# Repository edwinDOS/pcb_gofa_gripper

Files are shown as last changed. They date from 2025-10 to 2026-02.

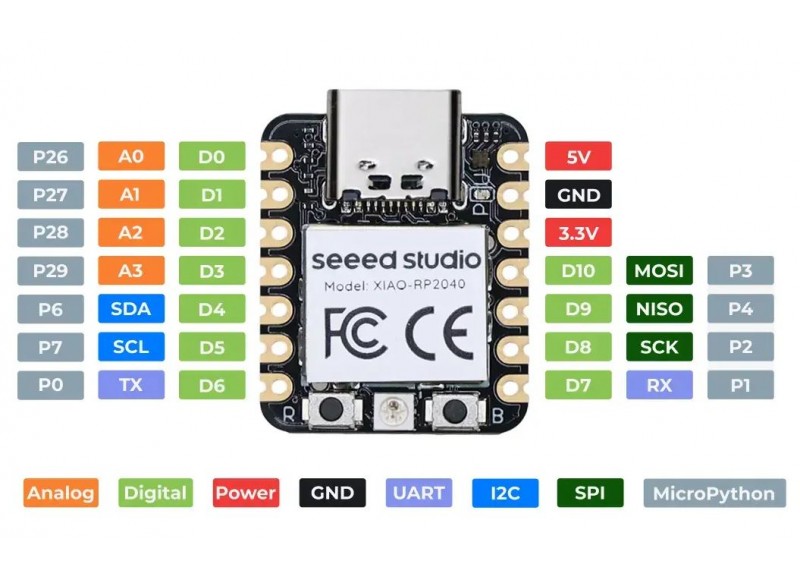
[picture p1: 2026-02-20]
XIAO_RP2040/ArduinoCode/seeed-studio-xiao-rp2040.jpg

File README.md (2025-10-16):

# pcb_gofa_gripper
This repository contains the PCB design for the ABB GOFA Gripper at UC3M

Desarrollado con:

Application: KiCad x64 on x64

Version: 9.0.1, release build

Libraries:
	wxWidgets 3.2.6
	FreeType 2.13.3
	HarfBuzz 10.2.0
	FontConfig 2.15.0
	libcurl/8.11.1-DEV Schannel zlib/1.3.1

Platform: Windows 10 (compilación 19045), edición de 64 bits, 64 bit, Little endian, wxMSW

Build Info:
	Date: Mar 30 2025 01:11:30
	wxWidgets: 3.2.6 (wchar_t,wx containers)
	Boost: 1.86.0
	OCC: 7.8.1
	Curl: 8.11.1-DEV
	ngspice: 44
	Compiler: Visual C++ 1942 without C++ ABI
	KICAD_IPC_API=ON

Locale: 
	Lang: es_ES
	Enc: UTF-8
	Num: 1.234,5
	Encoded кΩ丈: D0BACEA9E4B888 (sys), D0BACEA9E4B888 (utf8)

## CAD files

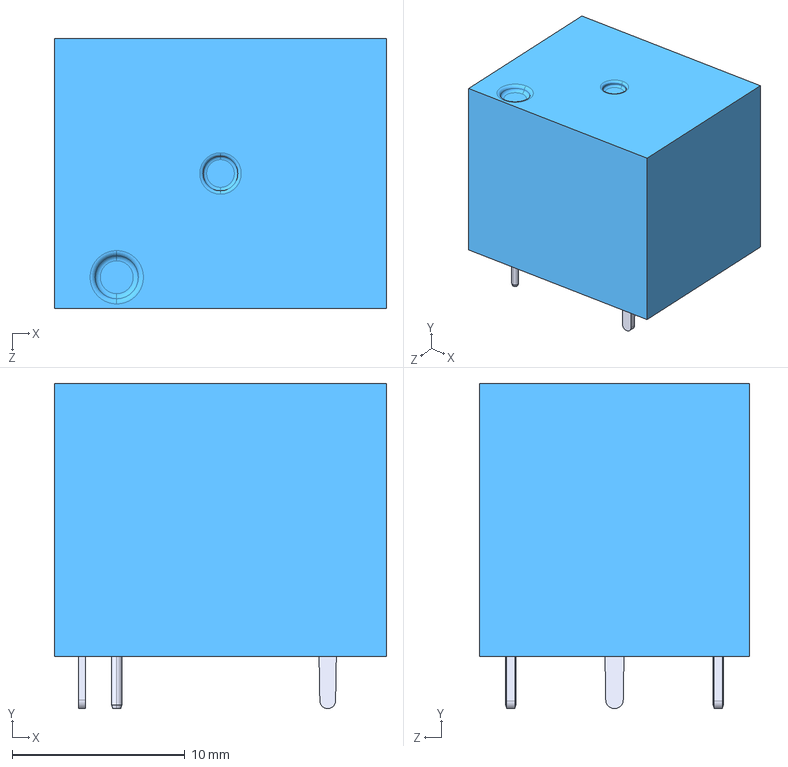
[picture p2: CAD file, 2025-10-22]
ArduinoNano/SRD-05VDC-SL-C/SRD-05VDC-SL-C.step
19.2 x 18.8 x 15.6 mm

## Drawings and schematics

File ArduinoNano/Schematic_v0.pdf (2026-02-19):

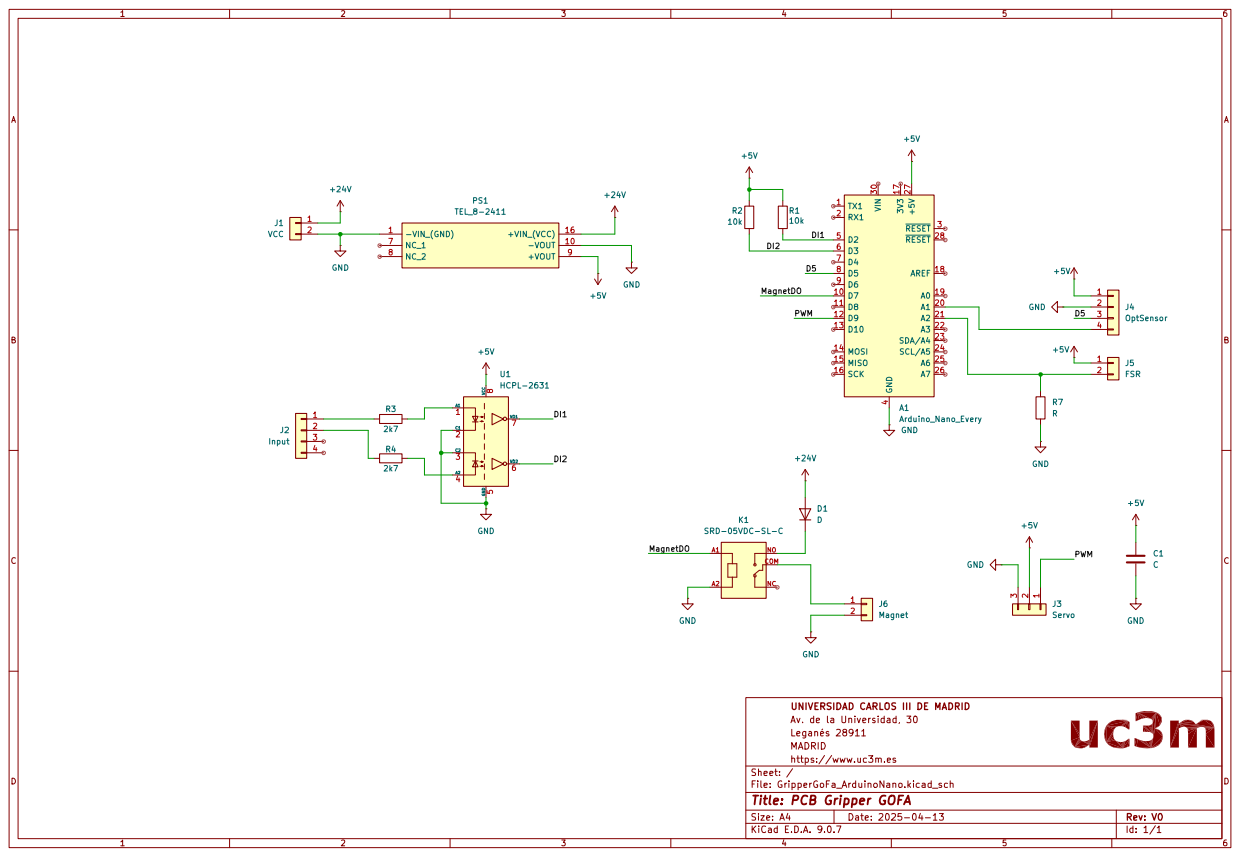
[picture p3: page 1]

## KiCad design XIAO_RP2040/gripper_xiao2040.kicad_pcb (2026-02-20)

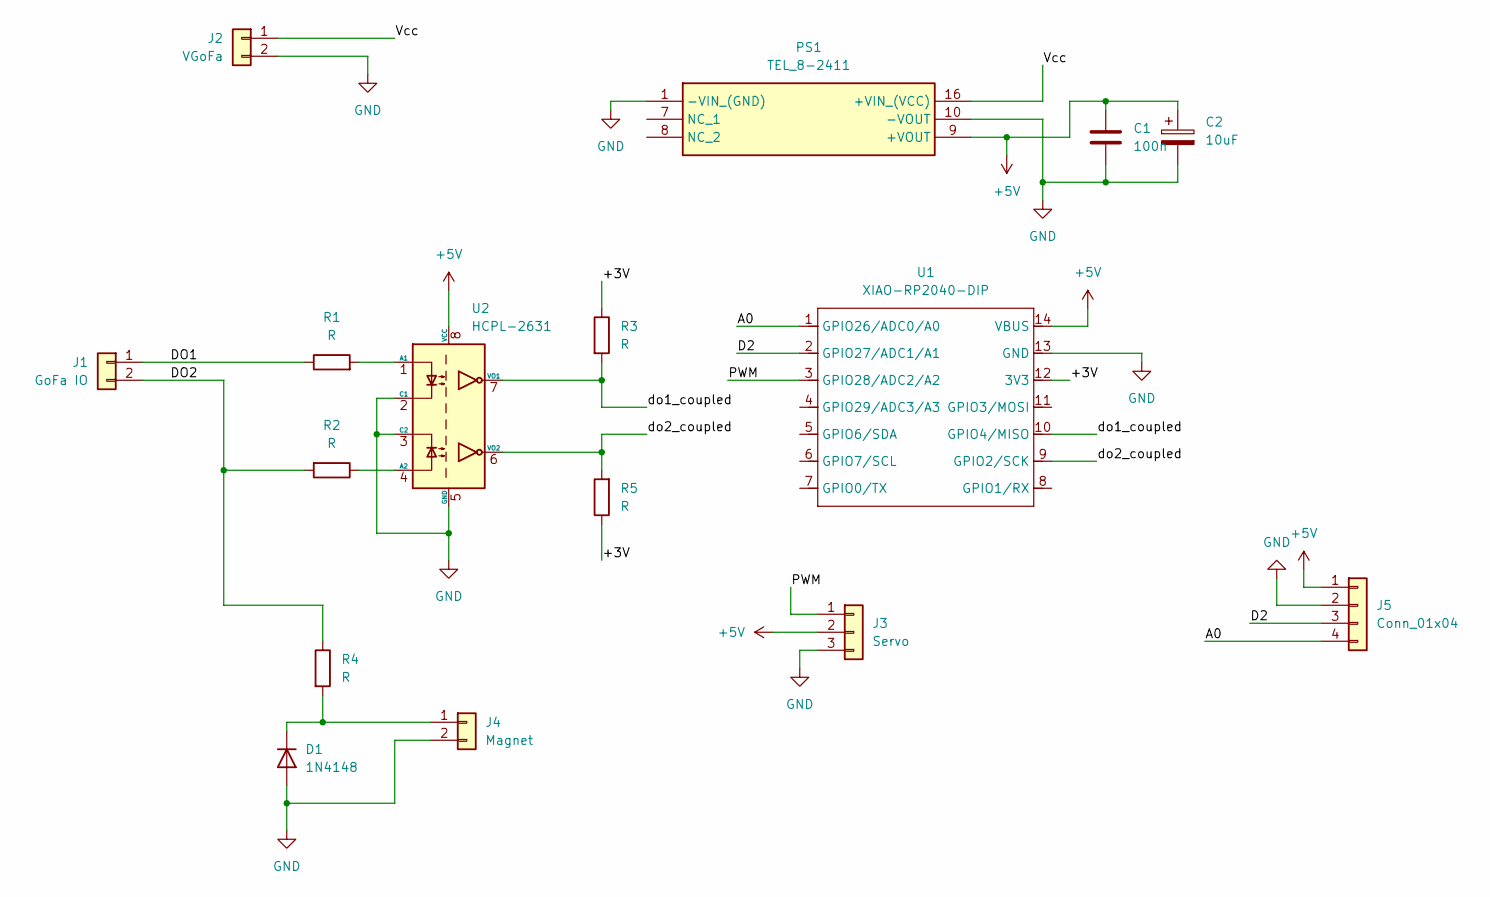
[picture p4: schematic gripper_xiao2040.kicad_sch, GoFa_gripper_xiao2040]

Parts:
C1: 100n; C_1210_3225Metric
C2: 10uF; CP_Radial_D4.0mm_P1.50mm
D1: 1N4148; D_DO-35_SOD27_P7.62mm_Horizontal
J1: GoFa IO; PinHeader_1x02_P2.54mm_Vertical
J2: VGoFa; PinSocket_1x02_P2.54mm_Vertical
J3: Servo; PinHeader_1x03_P2.54mm_Vertical
J4: Magnet; PinHeader_1x02_P2.54mm_Vertical
J5: Conn_01x04; PinHeader_1x04_P2.54mm_Vertical
PS1: TEL_8-2411; TEL82411; Manufacturer_Part_Number TEL 8-2411; Mouser Part Number 495-TEL8-2411
R1, R2, R3, R4, R5: R; R_1210_3225Metric
U1: XIAO-RP2040-DIP
U2: HCPL-2631; DIP-8_W7.62mm

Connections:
+5V: C1.1, C2.1, J3.2, J5.1, PS1.9 (+VOUT), U1.14 (VBUS), U2.8 (VCC)
/+3V: R3.1, R5.1, U1.12 (3V3)
/A0: J5.4, U1.1 (GPIO26/ADC0/A0)
/D2: J5.3, U1.2 (GPIO27/ADC1/A1)
/DO1: J1.1, R1.1
/DO2: J1.2, R2.2, R4.1
/PWM: J3.1, U1.3 (GPIO28/ADC2/A2)
/Vcc: J2.1, PS1.16 (+VIN_(VCC))
/do1_coupled: R3.2, U1.10 (GPIO4/MISO), U2.7 (VO1)
/do2_coupled: R5.2, U1.9 (GPIO2/SCK), U2.6 (VO2)
GND: C1.2, C2.2, D1.2 (A), J2.2, J3.3, J4.2, J5.2, PS1.1 (-VIN_(GND)), PS1.10 (-VOUT), U1.13 (GND), U2.2 (C1), U2.3 (C2), U2.5 (GND)
unnamed: D1.1 (K), J4.1, R4.2
unnamed: R1.2, U2.1 (A1)
unnamed: R2.1, U2.4 (A2)

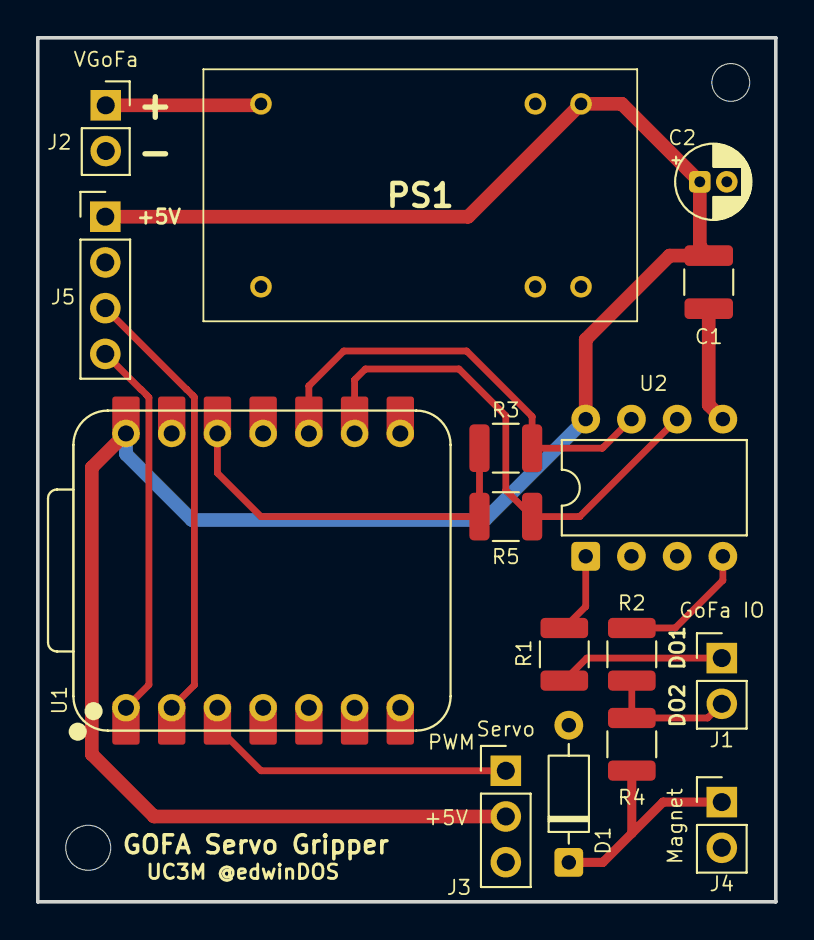
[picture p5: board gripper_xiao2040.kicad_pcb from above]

Board: 2 copper layers, 41.0 x 48.0 mm, 16 parts (0 on the bottom side), 14 nets.

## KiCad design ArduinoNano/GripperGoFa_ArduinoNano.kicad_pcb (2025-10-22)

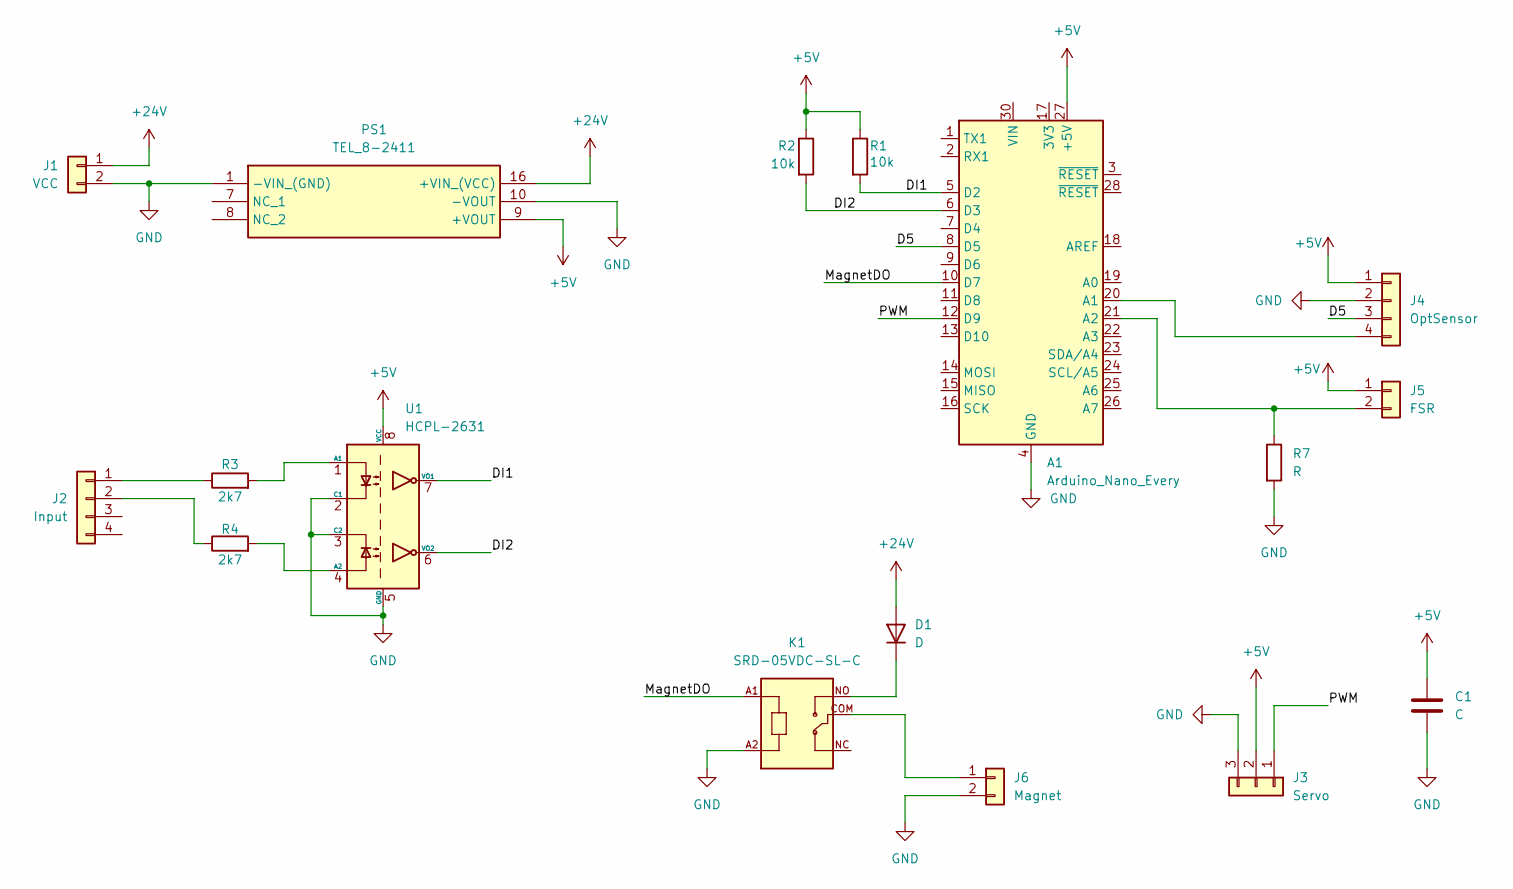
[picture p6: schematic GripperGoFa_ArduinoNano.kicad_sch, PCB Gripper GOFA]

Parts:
A1: Arduino_Nano_Every; Arduino_Nano
C1: C; C_1210_3225Metric
D1: D
J1: VCC; PinSocket_1x02_P2.54mm_Vertical
J2: Input; PinHeader_1x04_P2.54mm_Vertical
J3: Servo; PinSocket_1x03_P2.54mm_Horizontal
J4: OptSensor; PinHeader_1x04_P2.54mm_Vertical
J5: FSR; PinSocket_1x02_P2.54mm_Vertical
J6: Magnet; PinSocket_1x02_P2.54mm_Vertical
K1: SRD-05VDC-SL-C; RELAY_SRD-05VDC-SL-C
PS1: TEL_8-2411; TEL82411; Manufacturer_Part_Number TEL 8-2411; Mouser Part Number 495-TEL8-2411
R1, R2: 10k; R_1210_3225Metric
R3, R4: 2k7; R_1210_3225Metric
R7: R; R_1210_3225Metric_Pad1.30x2.65mm_HandSolder
U1: HCPL-2631; DIP-8_W7.62mm

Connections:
+5V: A1.27 (+5V), C1.1, J3.2, J4.1, J5.1, PS1.9 (+VOUT), R1.1, R2.1, U1.8 (VCC)
+24V: D1.2 (A), J1.1, PS1.16 (+VIN_(VCC))
/D5: A1.8 (D5), J4.3
/DI1: A1.5 (D2), R1.2, U1.7 (VO1)
/DI2: A1.6 (D3), R2.2, U1.6 (VO2)
/MagnetDO: A1.10 (D7), K1.A1
/PWM: A1.12 (D9), J3.1
GND: A1.4 (GND), A1.29 (GND), C1.2, J1.2, J3.3, J4.2, J6.2, K1.A2, PS1.1 (-VIN_(GND)), PS1.10 (-VOUT), R7.2, U1.2 (C1), U1.3 (C2), U1.5 (GND)
unnamed: A1.20 (A1), J4.4
unnamed: A1.21 (A2), J5.2, R7.1
unnamed: D1.1 (K), K1.NO
unnamed: J2.1, R3.1
unnamed: J2.2, R4.1
unnamed: J6.1, K1.COM
unnamed: R3.2, U1.1 (A1)
unnamed: R4.2, U1.4 (A2)

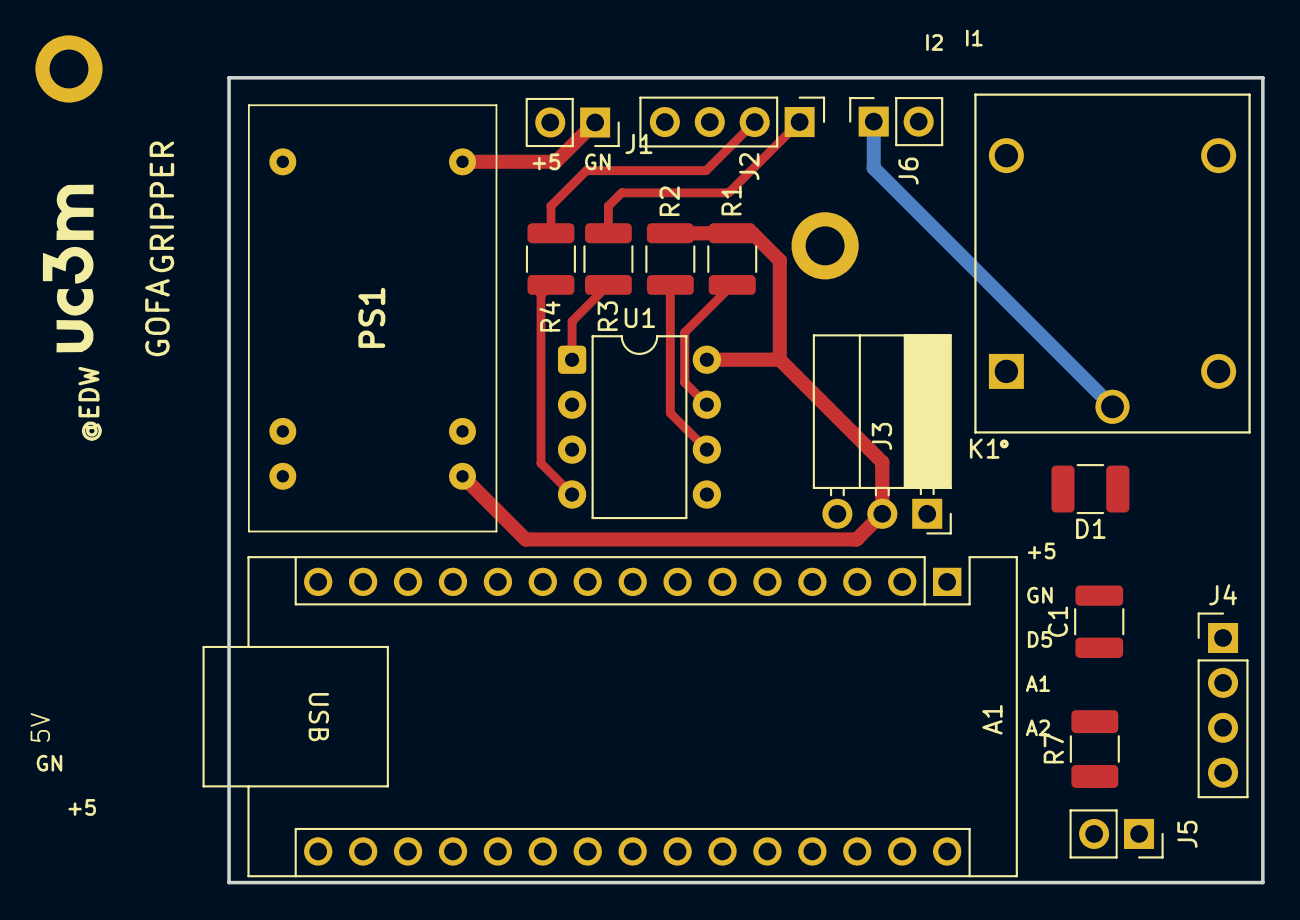
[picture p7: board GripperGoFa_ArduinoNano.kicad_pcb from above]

Board: 2 copper layers, 58.5 x 45.5 mm, 20 parts (0 on the bottom side), 16 nets.

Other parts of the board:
G: LOGO
H2: MountingHole; MountingHole_2.2mm_M2_DIN965_Pad
H2#2: MountingHole_2.2mm_M2_DIN965_Pad

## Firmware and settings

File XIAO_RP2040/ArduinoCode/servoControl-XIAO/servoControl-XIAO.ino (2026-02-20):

/*
This code is used to control the gripper of GOFA robot
The target arduino board is the Nano v3
Author: edwinDOS
*/

// Incluímos la librería para poder controlar el servo
#include <Servo.h>

Servo myservo;               // create servo object to control a servo
int ledPin = 13;             // LED connected to digital pin 13
int do1Pin = 9;              // robot output 1 connected to digital pin D9
int do2Pin = 8;              // robot output 2 connected to digital pin D8
int do1State = 0;            // variable to store the read value
int do2State = 0;            // variable to store the read value
bool gripperStatus = false;  //flag to identify the gripper status
int pos = 0;                 // variable to store the servo position

void setup() {
  myservo.attach(2);        // Iniciamos el servo para que empiece a trabajar con el pin D2 GPIO28 como salida PWM
  pinMode(ledPin, OUTPUT);  // sets the digital pin 13 as output
  pinMode(do1Pin, INPUT);   // sets the digital pin D9 as input
  pinMode(do2Pin, INPUT);   // sets the digital pin D8 as input
  myservo.write(180);       // moves servo to open position for initialization
  // initialize serial communication:
  //Serial.begin(9600); // Uncomment to debug by console
}

void loop() {

  do1State = digitalRead(do1Pin);  // read the input from the robot via DO1 signal
  do2State = digitalRead(do2Pin);  // read the input from the robot via DO2 signal
  digitalWrite(ledPin, do1State);  // sets the LED to the DI1's value

  //Serial.print("DO2: ");
  //Serial.println(do2State);

  if (do1State == 0 && gripperStatus == true) {
    for (pos = 0; pos <= 180; pos += 1) {  // goes from 0 degrees to 180 degrees
      // in steps of 1 degree
      myservo.write(pos);  // tell servo to go to position in variable 'pos'
      digitalWrite(ledPin, 1);
      delay(15);  // waits 15 ms for the servo to reach the position
    }
    gripperStatus = false;  //
  }

  if (do1State == 1 && gripperStatus == false) {
    for (pos = 180; pos >= 0; pos -= 1) {  // goes from 180 degrees to 0 degrees
      myservo.write(pos);                  // tell servo to go to position in variable 'pos'
      digitalWrite(ledPin, 0);
      delay(15);  // waits 15 ms for the servo to reach the position
    }
    gripperStatus = true;  // Gripper closed
  }
}

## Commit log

2025-09-19 first version of gripper pcb for Arduino Nano
    [GripperGoFa_ArduinoNano.kicad_pcb, GripperGoFa_ArduinoNano.kicad_sch]
2025-10-22 update components
    [GripperGoFa_ArduinoNano.kicad_pcb, GripperGoFa_ArduinoNano.kicad_sch, SRD-05VDC-SL-C.step]
2025-10-22 test changes
    [GripperGoFa_ArduinoNano.kicad_pcb]
2025-10-22 test2 changes
    [GripperGoFa_ArduinoNano.kicad_pcb]
2026-02-19 New PCB version based on XIAO-RP2040
    [GripperGoFa_ArduinoNano.kicad_pcb, GripperGoFa_ArduinoNano.kicad_sch, SRD-05VDC-SL-C.step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]
2026-02-20 Improving PCB routing and including Arduino code
    [gripper_xiao2040.kicad_pcb, gripper_xiao2040.kicad_sch]
2026-10-23 PCB design complete and built. Arduino code still testing
